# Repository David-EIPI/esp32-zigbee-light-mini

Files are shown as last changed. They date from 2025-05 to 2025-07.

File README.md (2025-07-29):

# esp32-zigbee-light-mini

Compact version of the remotely controlled indoor light based on ESP32-H2 and Home Assistant.

## Overview

This is a compact version of the [esp32-zigbee-light](https://github.com/David-EIPI/esp32-zigbee-light "Remotely controlled indoor light powered by ESP32-H2"), small enough to fit into an in-ceiling electrical box, enabling neat conversion of a standard ceiling fixture into a smart light.

This project utilizes a compact WROOM-03 module with an edge connector. The overall design follows [esp32-zigbee-light](https://github.com/David-EIPI/esp32-zigbee-light "Remotely controlled indoor light powered by ESP32-H2").

## Firmware

The firmware is written in C and built with `idf.py`. It implements a zero-crossing detector for TRIAC-based dimming and supports the **HLK-LD2420S** mmWave motion sensor with adjustable sensing distance. The firmware exposes 7 endpoints and 13 clusters:

* **6 Analog Output clusters** (configuration)
* **2 Analog Input clusters** (presence detection distance, calibration control)
* **2 Binary Input clusters** (motion state, light state)
* **1 Multistate Value cluster** (operation mode)
* **1 OnOff cluster** (dimming enable control)
* **1 Temperature cluster** (MCU internal temperature)

This design includes an additional temperature cluster due to the compact, enclosed setup. Monitoring internal temperature becomes important in this system.

See [here](https://github.com/David-EIPI/esp32-zigbee-light/blob/main/BUILD.md) instructions on building the firmware using `idf.py` on Linux.

### Sensor calibration

In this compact design, the LD2420s motion sensor has shown somewhat unstable output. Even without any motion, it occasionally "detects" activity at random distances. This likely results from EMI generated by the power supply, the microcontroller core, or the radio. Fortunately, the LD2420s sensor supports programmable signal thresholds, allowing for in-place calibration. The calibration approach and initial code are based on the [ESPHome LD2420 plugin](https://github.com/esphome/esphome/blob/dev/esphome/components/ld2420 "ESPHome LD2420 plugin").

Calibration is initiated by writing a numerical value (interpreted as calibration duration in seconds) to the Analog Input cluster at Endpoint 2. A ZHA quirk can provide a button to conveniently start calibration.

## Hardware

Schematics and PCB layout were created using KiCad. The board integrates an AC-DC power supply, ESP32-H2 controller, LD2420s sensor, TRIAC, and associated control circuitry. Input protection includes a current fuse, thermal fuse, and a TVS diode. The TRIAC control circuit matches the one in [esp32-zigbee-light](https://github.com/David-EIPI/esp32-zigbee-light "Remotely controlled indoor light powered by ESP32-H2").

### Power supply

The largest component on the board is the AC-DC converter.
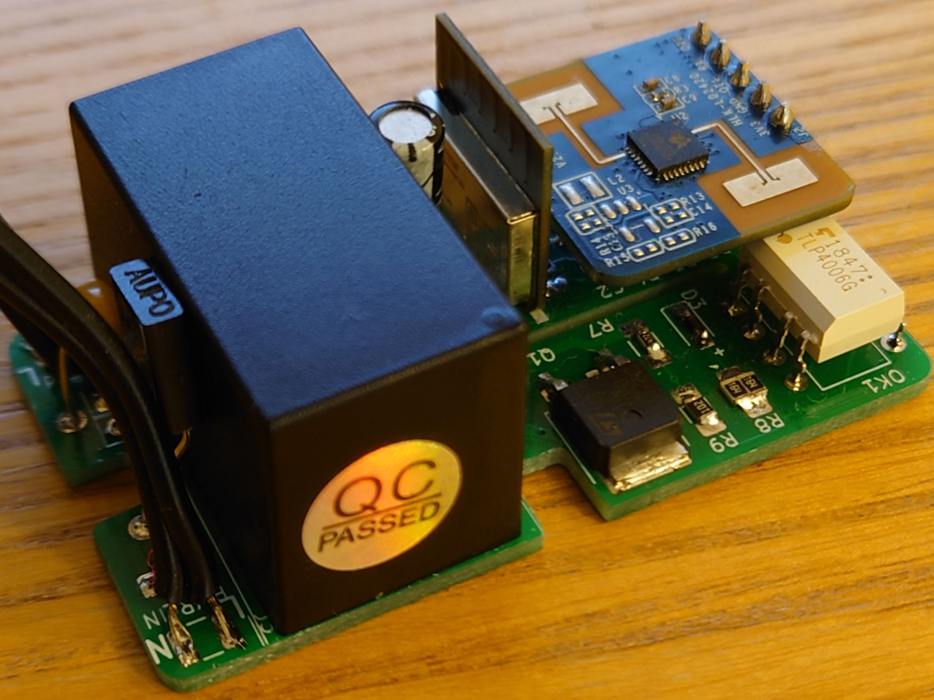
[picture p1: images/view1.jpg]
Board view Assembled board, AC-DC view

This is the HLK-2M03 from HiLink, an isolated 3.3 V, 600 mA converter.  Measured ESP32 consumption is approximately 20 mA during RF transmission, and the documented LD2420s consumption averages around 50 mA, with occasional peaks of about 70 mA. Including the optocoupler current, total demand should not exceed 100 mA. HLK-2M03 is somewhat oversized for this design but smaller modules appear unavailable.

### ESP32-H2 Wroom-03 module

The module is designed for vertical mounting to conserve PCB space. Its height above the board is 16 mm, which is lower than the AC-DC module, thus not affecting the overall dimensions.

Soldering this module presented some challenges:

First, the slot recommended by the datasheet is excessively wide, causing the module to fit loosely and leaving large air gaps difficult to bridge with solder. To resolve this, I soldered short wire segments to the pads as guides, but the result still looks ugly. I wonder if wave soldering would work for this module.

Second, programming is performed via small test pads (USB or serial port). In the datasheet I did not find any recommendations regarding manufacturer-supported programming fixtures. While some users create custom 3D-printed jigs, I opted to solder free-hanging wires directly to the module’s USB pads, enabling programming and debugging after board assembly.
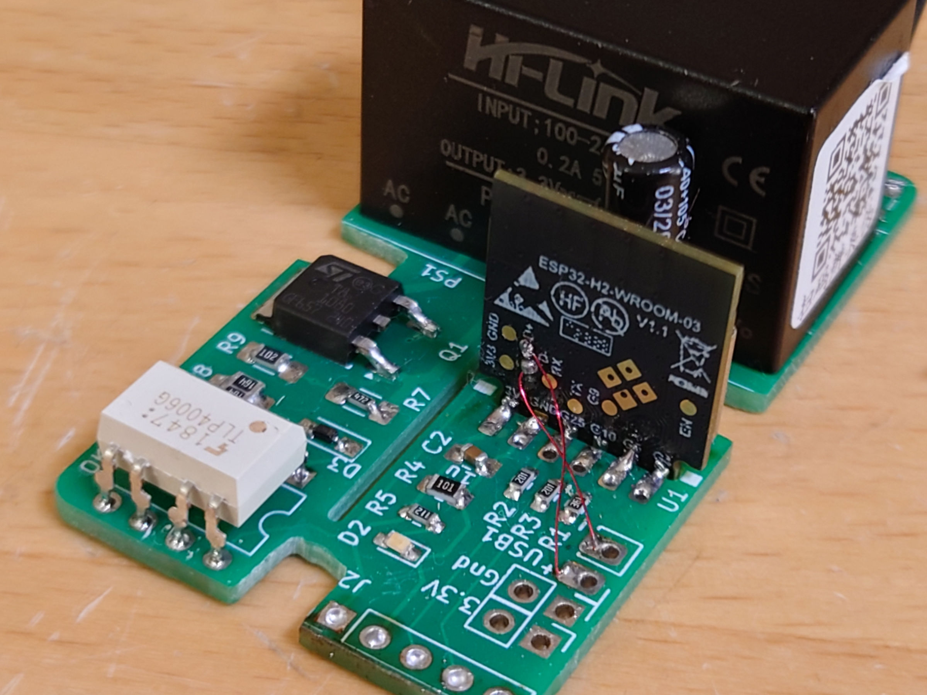
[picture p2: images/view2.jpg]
ESP32-H2 Wroom module Assembled board, ESP32H2 view


### Enclosure

The PCB was designed to fit one of the many enclosures sold on AliExpress. Many sellers offer identical boxes; I purchased this one below:
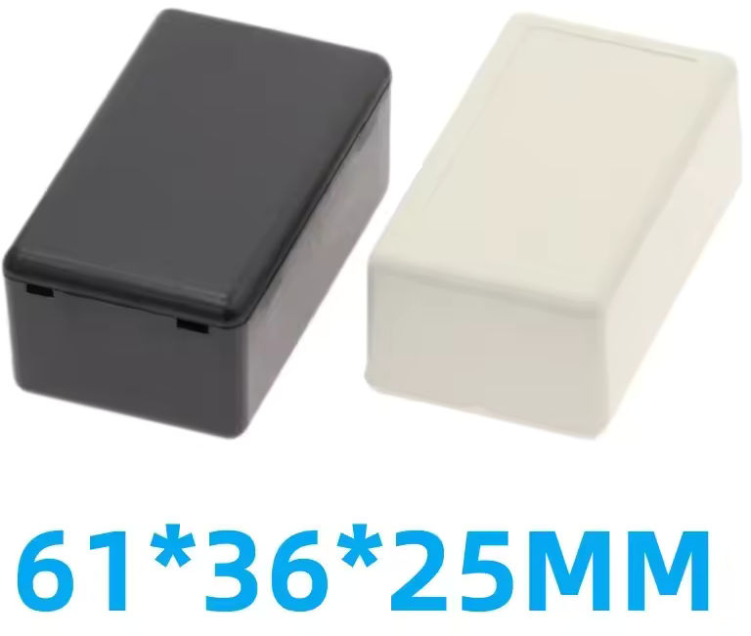
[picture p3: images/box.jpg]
Enclosure box


The assembled board fits almost perfectly, though slight filing was necessary on the cutouts made for the mounting posts. The inner height of the enclosure just accommodates the AC-DC converter, leaving insufficient room to place the board on top of the mounting posts. Instead, I made small cutouts around the posts, allowing the board to sit flat at the bottom.
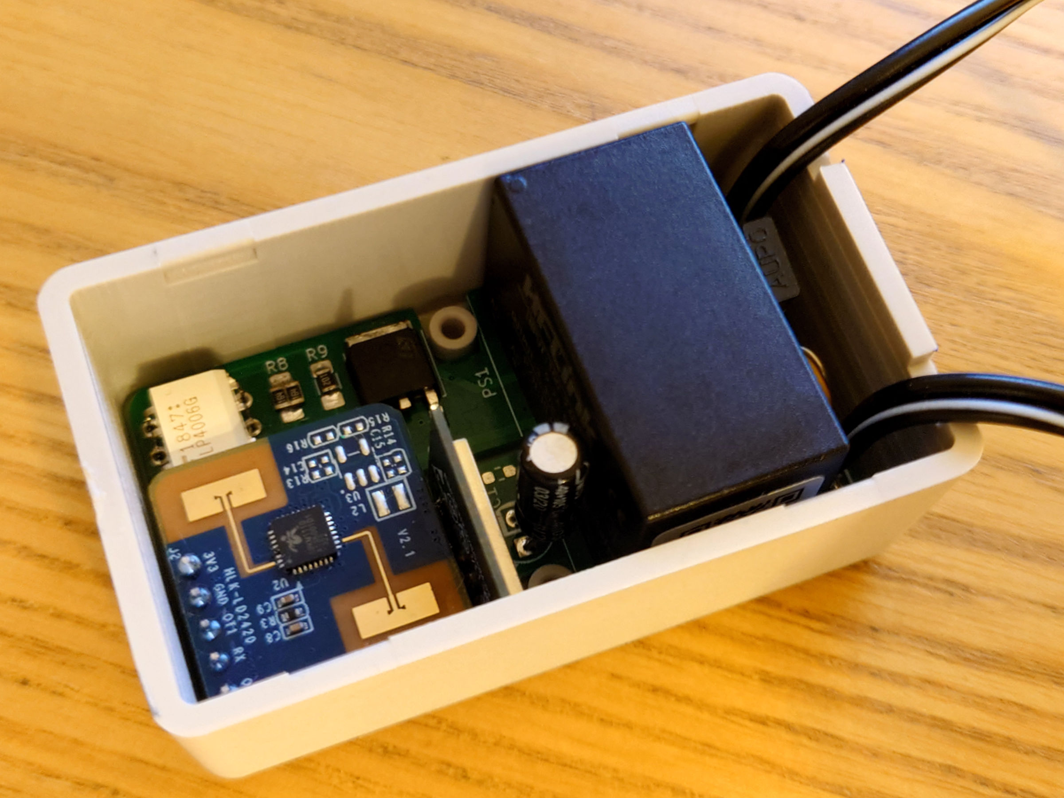
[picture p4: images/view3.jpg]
Assembled board in enclosure Assembled board in the enclosure


To ensure proper fit, the board's bottom side needed to remain completely flat. The AC-DC converter’s leads were trimmed flush, and minimal solder was used to avoid bulges. All other through-hole components were soldered from the top side while pressing the board firmly onto a flat surface, which is why they “hover” above the board surface.
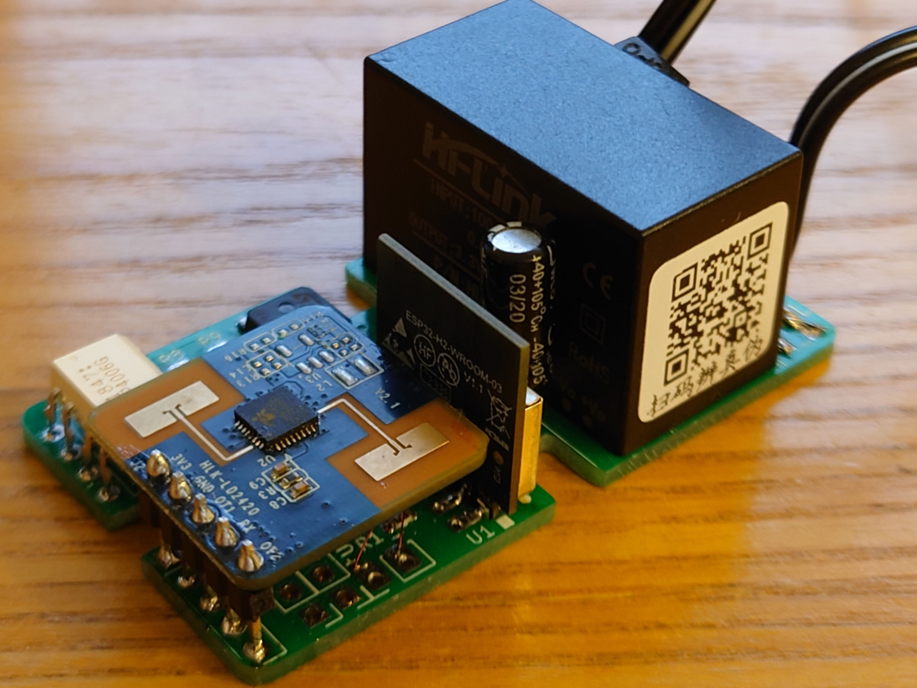
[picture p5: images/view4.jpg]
Assembled board, front view


The enclosure features convenient side-wall cutouts for wiring; however, matching cutouts on the lid’s inner rim were missing and had to be manually added. Below is the final assembled enclosure, shown alongside a CR2032 battery for scale reference:
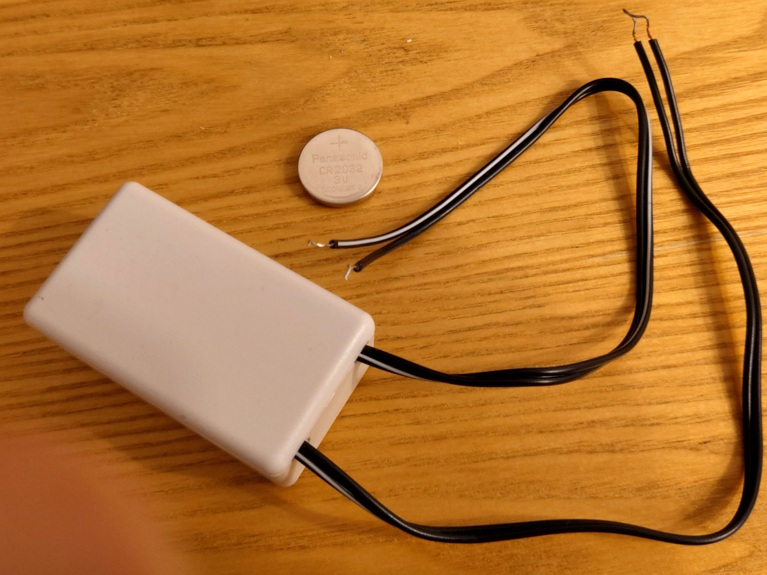
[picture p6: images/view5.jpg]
Assembled box


## ZHA Quirk

The ZHA quirk supporting this device is essentially identical to that in the [esp32-zigbee-light](https://github.com/David-EIPI/esp32-zigbee-light "Remotely controlled indoor light powered by ESP32-H2") project, with only minor additions required to enable sensor calibration requests. This functionality can be implemented in two ways:

* Using the `.number()` method, which defaults to a CONFIG entity displayed as a slider. Setting this slider triggers calibration for the selected duration.
* Using the `.write_attr_butt()` method, creating a button that sets a predefined attribute value upon pressing.

I have left both methods are in the quirk file for reference.
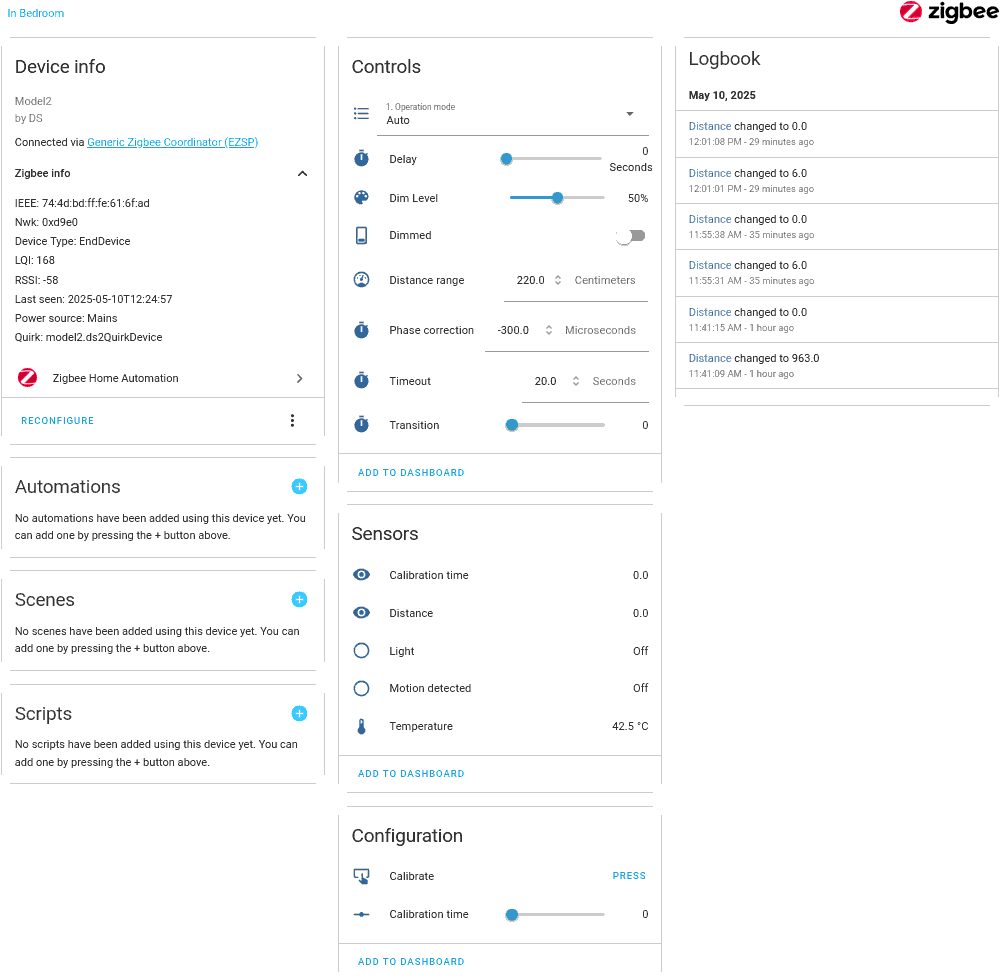
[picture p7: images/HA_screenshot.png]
Home Assistant device page


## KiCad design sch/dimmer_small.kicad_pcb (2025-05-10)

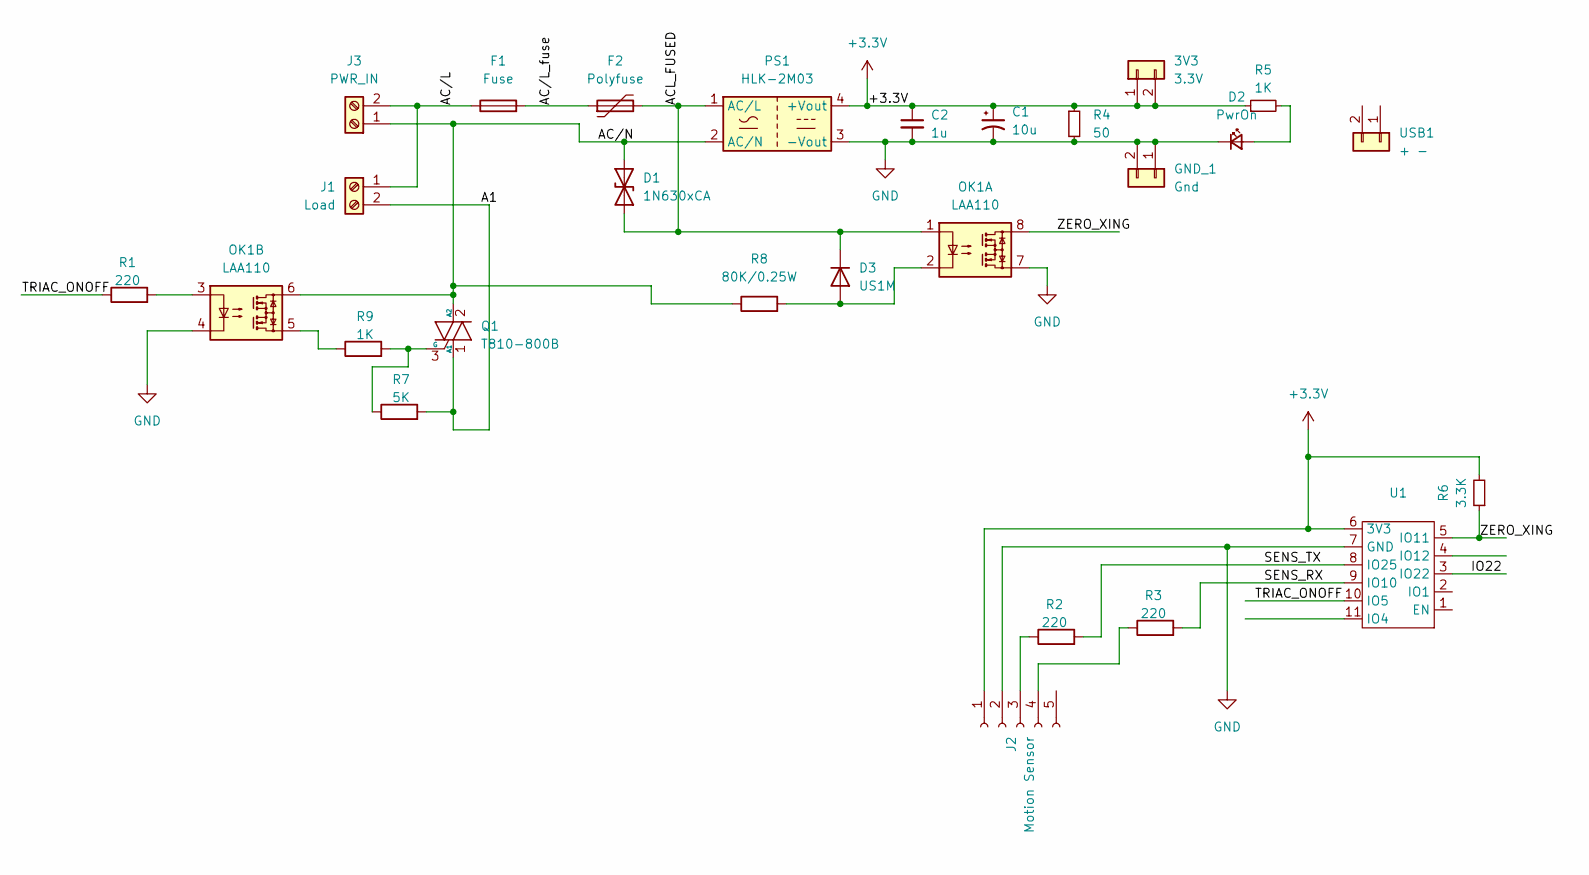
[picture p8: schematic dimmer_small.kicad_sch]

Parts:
3V3: 3.3V; PinHeader_1x02_P2.54mm_Vertical
C1: 10u; CP_Radial_D5.0mm_P2.50mm
C2: 1u; C_0805_2012Metric_Pad1.18x1.45mm_HandSolder
D1: 1N630xCA; PinHeader_2x01_P2.54mm_Vertical
D2: PwrOn; LED_0603_1608Metric_Pad1.05x0.95mm_HandSolder
D3: US1M; Nexperia_CFP3_SOD-123W
F1: Fuse; Fuse_1206_3216Metric_Pad1.42x1.75mm_HandSolder
F2: Polyfuse; Fuse_Bourns_MF-RHT1000
GND_1: Gnd; PinHeader_1x02_P2.54mm_Vertical
J1: Load; Fuse_1210_3225Metric
J2: Motion Sensor; PinHeader_1x05_P2.54mm_Vertical
J3: PWR_IN; Fuse_1210_3225Metric
OK1: LAA110; DIP-8_W7.62mm
PS1: HLK-2M03; Converter_ACDC_Hi-Link_HLK-2Mxx
Q1: T810-800B; TO-252-2
R1, R2, R3: 220; R_0603_1608Metric_Pad0.98x0.95mm_HandSolder
R4: 50; R_0805_2012Metric_Pad1.20x1.40mm_HandSolder
R5: 1K; R_0603_1608Metric_Pad0.98x0.95mm_HandSolder
R6: 3.3K; R_0603_1608Metric_Pad0.98x0.95mm_HandSolder
R7: 5K; R_1206_3216Metric_Pad1.30x1.75mm_HandSolder
R8: 80K/0.25W; R_1206_3216Metric_Pad1.30x1.75mm_HandSolder
R9: 1K; R_1206_3216Metric_Pad1.30x1.75mm_HandSolder
U1: ESP32-H2-WROOM-03
USB1: + -; PinHeader_1x02_P2.54mm_Vertical

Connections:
+3.3V: 3V3.1, 3V3.2, C1.1, C2.1, J2.1, PS1.4 (+Vout), R4.1, R5.1, R6.2, U1.6 (3V3)
/A1: J1.2, Q1.1 (A1), R7.2
/ACL_FUSED: D1.1 (A1), D3.1 (K), F2.2, OK1.1, PS1.1 (AC/L)
/AC/L: F1.1, J1.1, J3.2
/AC/L_fuse: F1.2, F2.1
/AC/N: D1.2 (A2), J3.1, OK1.6, PS1.2 (AC/N), Q1.2 (A2), R8.1
/IO22: U1.3 (IO22)
/SENS_RX: R3.2, U1.9 (IO10)
/SENS_TX: R2.2, U1.8 (IO25)
/TRIAC_ONOFF: R1.1, U1.10 (IO5)
/ZERO_XING: OK1.8, R6.1, U1.5 (IO11)
GND: C1.2, C2.2, D2.1 (K), GND_1.1, GND_1.2, J2.2, OK1.4, OK1.7, PS1.3 (-Vout), R4.2, U1.7 (GND)
unnamed: D2.2 (A), R5.2
unnamed: D3.2 (A), OK1.2, R8.2
unnamed: J2.3, R2.1
unnamed: J2.4, R3.1
unnamed: OK1.3, R1.2
unnamed: OK1.5, R9.1
unnamed: Q1.3 (G), R7.1, R9.2

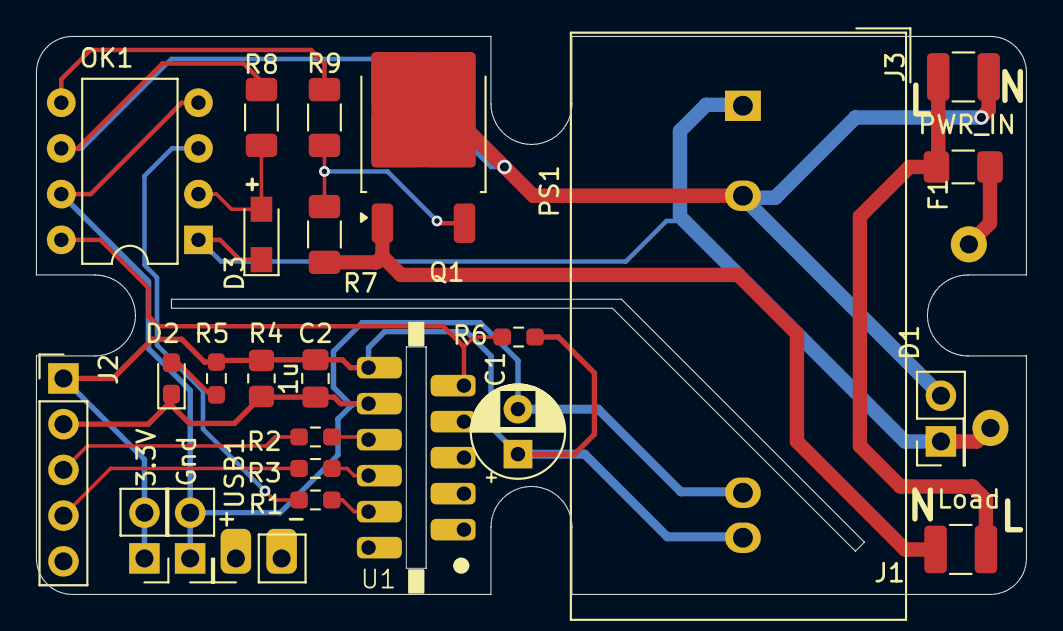
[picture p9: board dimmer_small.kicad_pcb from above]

Board: 2 copper layers, 55.0 x 31.0 mm, 26 parts (1 on the bottom side), 18 nets.

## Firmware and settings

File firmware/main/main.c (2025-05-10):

/*
 * SPDX-FileCopyrightText: 2021-2024 Espressif Systems (Shanghai) CO LTD
 *
 * SPDX-License-Identifier: CC0-1.0
 *
 * Zigbee HA_on_off_light Example
 *
 * This example code is in the Public Domain (or CC0 licensed, at your option.)
 *
 * Unless required by applicable law or agreed to in writing, this
 * software is distributed on an "AS IS" BASIS, WITHOUT WARRANTIES OR
 * CONDITIONS OF ANY KIND, either express or implied.
 */

#include "freertos/FreeRTOS.h"
#include "freertos/task.h"
#include "esp_check.h"
#include "esp_zigbee_core.h"
#include "esp_log.h"
#include "nvs_flash.h"
#include "ha/esp_zigbee_ha_standard.h"
#include "driver/gpio.h"
#include "driver/temperature_sensor.h"
#include "main.h"
#include "clock.h"
#include "ld2420_comm.h"
#include "triac_dimmer.h"

#if !defined ZB_ED_ROLE
#error Define ZB_ED_ROLE in idf.py menuconfig to compile light (End Device) source code.
#endif

static const char *TAG = "APP_MAIN";



enum _operation_modes {
    OPMODE_AUTO = 1,
    OPMODE_ON = 2,
    OPMODE_OFF = 3,
};

static uint16_t operation_mode = OPMODE_AUTO;
static bool enable_dimmed_mode = false;
static int prev_motion_detected = 0;
static int light_state = 1, prev_light_state = 0;
static int32_t light_delay = 2; // seconds, delay after motion detection
static int32_t light_timeout = 10; // seconds, time to keep the light on after motion has stopped
static int32_t light_dim_level = DIM_LEVEL_MAX/2;

static uint64_t light_time_on = 0;
static uint64_t no_motion_time = 0;
static gptimer_handle_t timer = 0;
static const uint32_t timer_resolution = 10 * 1000;

static const unsigned indication_led_pin = 13;

TaskHandle_t dimmerTaskHandle = NULL;

static temperature_sensor_handle_t temp_handle = NULL;
static float temperature_sensor_value = 0;

/********************* Define functions **************************/
static void bdb_start_top_level_commissioning_cb(uint8_t mode_mask)
{
    ESP_ERROR_CHECK(esp_zb_bdb_start_top_level_commissioning(mode_mask));
}

static const int ZB_INIT_FAIL_COUNT_TO_REBOOT = 60;
static const int ZB_ZDO_FAIL_COUNT_TO_REBOOT = 10;
static int zb_fail_count = 0;


static struct {
    char     description[16];
    float    min_present;
    float    max_present;
    float    present_value;
    float    resolution;
    uint16_t status_flags;
    uint16_t units;
    uint32_t app_type;
    volatile int32_t *value_ptr;
    char     nvs_key[8];
} analog_output_attr_values[] = {
    {
    .description = "\x07" "Timeout",
    .min_present = 1,
    .max_present = 3600,
    .present_value = 20,
    .resolution = 1,
    .status_flags = 0,
    .units = 73, /* 73 = seconds */
    .app_type = 14 << 16, /* 14 = timer */
//    .value_ptr = &motionTimeout,
    .value_ptr = &light_timeout,
    .nvs_key = "AO_00",
    },

    {
    .description = "\x05" "Delay",
    .min_present = 0,
    .max_present = 20,
    .present_value = 2,
    .resolution = 1,
    .status_flags = 0,
    .units = 73, /* 73 = seconds */
    .app_type = 14 << 16, /* 14 = timer */
    .value_ptr = &light_delay,
    .nvs_key = "AO_01",
    },

    {
    .description = "\x0e" "Distance range",
    .min_present = 1,
    .max_present = 1000,
    .present_value = 200,
    .resolution = 1,
    .status_flags = 0,
    .units = 118, /* 118 = cm */
    .app_type = 2 << 16, /* 2 = Gauge */
    .value_ptr = &motionThreshold,
    .nvs_key = "AO_02",
    },

    {
    .description = "\x09" "Dim level",
    .min_present = 0,
    .max_present = 100,
    .present_value = 50,
    .resolution = 1,
    .status_flags = 0,
    .units = 98, /* 98 = % */
    .app_type = 15 << 16, /* 15 = palette */
    .value_ptr = &light_dim_level,
    .nvs_key = "AO_03",
    },

    {
    .description = "\x0b" "Phase corr.",
    .min_present = -10000,
    .max_present = 10000,
    .present_value = 0,
    .resolution = 1,
    .status_flags = 0,
    .units = 194, /* 194 = microseconds */
    .app_type = 14 << 16, /* 15 = timer */
    .value_ptr = &phaseCorrection_us,
    .nvs_key = "AO_04",
    },

    {
    .description = "\x0a" "Transition",
    .min_present = 0,
    .max_present = 15,
    .present_value = 0,
    .resolution = 1,
    .status_flags = 0,
    .units = 95,
    .app_type = 14 << 16, /* 15 = timer */
    .value_ptr = &transitionTime,
    .nvs_key = "AO_05",
    },


};



static struct {
    char     *states_text;
    char     description[16];
    uint16_t *present_value_ptr;
    uint16_t status_flags;
    uint16_t number_of_states;
    char     nvs_key[8];
} multistate_attr_values[] = {
    {

/* Binary format for the ZCL string array: 1. type; 2. count; 3. array of strings.
*/
    .states_text = "\x42"       /*ESP_ZB_ZCL_ATTR_TYPE_CHAR_STRING = 0x42 */
                    "\x04\x00"  /* Element count */
                    "\x04" "Auto"
                    "\x02" "On"
                    "\x03" "Off",
    .description = "\x0e" "Operation mode",
    .present_value_ptr = &operation_mode,
    .status_flags = 0,
    .number_of_states = 3,
    .nvs_key = "MV_00",
    }
};

char light_on_binary_desc[] = "\x0b" "Light is on";
char motion_binary_desc[] = "\x0f" "Motion detected";

const char ZB_STORAGE_NAMESPACE[] = "zb_storage";

static void init_gpio(void)
{
    const gpio_config_t io_conf = {
        .intr_type = GPIO_INTR_DISABLE,
        .mode = GPIO_MODE_OUTPUT,
        .pin_bit_mask = (1ULL << indication_led_pin),
        .pull_down_en = 0,
        .pull_up_en = 0,
    };

    gpio_config(&io_conf);
    gpio_set_level(indication_led_pin, 1);
}

/* Signal the dimmer task to disable its sync source and stop the timer
    to avoid light flash when the source pin is disabled at restart. */
static void stop_dimmer_and_restart(void)
{
    stopDimmer = 1;
    vTaskDelay(pdMS_TO_TICKS(200));
    esp_restart();
}


void esp_zb_app_signal_handler(esp_zb_app_signal_t *signal_struct)
{
    uint32_t *p_sg_p       = signal_struct->p_app_signal;
    esp_err_t err_status = signal_struct->esp_err_status;
    esp_zb_app_signal_type_t sig_type = *p_sg_p;
    uint8_t min_lqi;

    switch (sig_type) {
    case ESP_ZB_NLME_STATUS_INDICATION:
        ESP_LOGI(TAG, "%s, status: 0x%x\n", esp_zb_zdo_signal_to_string(sig_type), *(uint8_t *)esp_zb_app_signal_get_params(p_sg_p));
        break;
    case ESP_ZB_ZDO_SIGNAL_SKIP_STARTUP:
        ESP_LOGI(TAG, "Zigbee stack initialized");
        esp_zb_bdb_start_top_level_commissioning(ESP_ZB_BDB_MODE_INITIALIZATION);
        min_lqi = esp_zb_secur_network_min_join_lqi_get();
        ESP_LOGI(TAG, "Min LQI = %u", (unsigned)min_lqi);
        esp_zb_secur_network_min_join_lqi_set(0);
        break;
    case ESP_ZB_BDB_SIGNAL_DEVICE_FIRST_START:
    case ESP_ZB_BDB_SIGNAL_DEVICE_REBOOT:
        if (err_status == ESP_OK) {
            ESP_LOGI(TAG, "Device started up in %s factory-reset mode", esp_zb_bdb_is_factory_new() ? "" : "non");
            if (esp_zb_bdb_is_factory_new()) {
                ESP_LOGI(TAG, "Start network steering");
                esp_zb_bdb_start_top_level_commissioning(ESP_ZB_BDB_MODE_NETWORK_STEERING);
            } else {
                ESP_LOGI(TAG, "Device rebooted");
            }

            zb_fail_count = 0;
        } else {
            /* commissioning failed */

            if (ZB_INIT_FAIL_COUNT_TO_REBOOT <= zb_fail_count) {
                ESP_LOGI(TAG, "ZB init has failed too many times. Restarting.");
                stop_dimmer_and_restart();
                break;
            }

            ESP_LOGW(TAG, "Failed to initialize Zigbee stack (status: %s)", esp_err_to_name(err_status));
            esp_zb_scheduler_alarm((esp_zb_callback_t)bdb_start_top_level_commissioning_cb, ESP_ZB_BDB_MODE_INITIALIZATION, 1000);
            zb_fail_count += 1;
        }
        break;
    case ESP_ZB_BDB_SIGNAL_STEERING:
        if (err_status == ESP_OK) {
            esp_zb_ieee_addr_t extended_pan_id;
            esp_zb_get_extended_pan_id(extended_pan_id);
            ESP_LOGI(TAG, "Joined network successfully (Extended PAN ID: %02x:%02x:%02x:%02x:%02x:%02x:%02x:%02x, PAN ID: 0x%04hx, Channel:%d, Short Address: 0x%04hx)",
                     extended_pan_id[7], extended_pan_id[6], extended_pan_id[5], extended_pan_id[4],
                     extended_pan_id[3], extended_pan_id[2], extended_pan_id[1], extended_pan_id[0],
                     esp_zb_get_pan_id(), esp_zb_get_current_channel(), esp_zb_get_short_address());
        } else {
            ESP_LOGI(TAG, "Network steering was not successful (status: %s)", esp_err_to_name(err_status));
            esp_zb_scheduler_alarm((esp_zb_callback_t)bdb_start_top_level_commissioning_cb, ESP_ZB_BDB_MODE_NETWORK_STEERING, 1000);
        }
        break;
    case ESP_ZB_ZDO_SIGNAL_LEAVE:
        ESP_LOGI(TAG, "Leave and network steering initiated.");
//        esp_zb_zcl_reset_nvram_to_factory_default();
        esp_zb_bdb_reset_via_local_action();
        esp_zb_factory_reset();
        esp_zb_scheduler_alarm((esp_zb_callback_t)bdb_start_top_level_commissioning_cb, ESP_ZB_BDB_MODE_NETWORK_STEERING, 1000);
        break;
    case ESP_ZB_ZDO_DEVICE_UNAVAILABLE:
        if (ZB_ZDO_FAIL_COUNT_TO_REBOOT <= zb_fail_count) {
            ESP_LOGI(TAG, "ZDO device unavailable. Restarting.");
            stop_dimmer_and_restart();
            break;
        }
        zb_fail_count += 1;
        __attribute__ ((fallthrough));
    default:
        ESP_LOGI(TAG, "ZDO signal: %s (0x%x), status: %s", esp_zb_zdo_signal_to_string(sig_type), sig_type,
                 esp_err_to_name(err_status));
        break;
    }
}

static struct {
    char     description[16];
    float    min_present;
    float    max_present;
    float    present_value;
    float    resolution;
    uint16_t status_flags;
    uint16_t units;
    uint32_t app_type;
    volatile int32_t *value_ptr;
} analog_input_attr_values[] = {
    {
    .description = DISTANCE_SENSOR_DESC,
    .min_present = 0,
    .max_present = 1000,
    .present_value = 0,
    .resolution = 1,
    .status_flags = 0,
    .units = 118, /* 118 = cm */
    .app_type = 2 << 16, /* 2 = Gauge icon */
    },
    {
    .description = CALIBRATION_DESC,
    .min_present = 0,
    .max_present = 1000,
    .present_value = 0,
    .resolution = 1,
    .status_flags = 0,
    .units = 73, /* 73 = seconds */
    .app_type = 14 << 16, /* 14 = timer */
    .value_ptr = &calibrationTime,
    },
};

#define ANALOG_INPUT_ATTR_FIELD_OFFSET(field) (offsetof(typeof(analog_input_attr_values[0]), field))

static struct {
    int id;
    int offs;
    int access;
} analog_input_attr_offset[] = {
    { ESP_ZB_ZCL_ATTR_ANALOG_INPUT_DESCRIPTION_ID      , ANALOG_INPUT_ATTR_FIELD_OFFSET(description),   .access = ESP_ZB_ZCL_ATTR_ACCESS_READ_ONLY },
    { ESP_ZB_ZCL_ATTR_ANALOG_INPUT_MAX_PRESENT_VALUE_ID, ANALOG_INPUT_ATTR_FIELD_OFFSET(max_present),   .access = ESP_ZB_ZCL_ATTR_ACCESS_READ_ONLY },
    { ESP_ZB_ZCL_ATTR_ANALOG_INPUT_MIN_PRESENT_VALUE_ID, ANALOG_INPUT_ATTR_FIELD_OFFSET(min_present),   .access = ESP_ZB_ZCL_ATTR_ACCESS_READ_ONLY },
    { ESP_ZB_ZCL_ATTR_ANALOG_INPUT_PRESENT_VALUE_ID    , ANALOG_INPUT_ATTR_FIELD_OFFSET(present_value), .access = ESP_ZB_ZCL_ATTR_ACCESS_READ_WRITE | ESP_ZB_ZCL_ATTR_ACCESS_REPORTING },
    { ESP_ZB_ZCL_ATTR_ANALOG_INPUT_RESOLUTION_ID       , ANALOG_INPUT_ATTR_FIELD_OFFSET(resolution),    .access = ESP_ZB_ZCL_ATTR_ACCESS_READ_ONLY },
    { ESP_ZB_ZCL_ATTR_ANALOG_INPUT_STATUS_FLAGS_ID     , ANALOG_INPUT_ATTR_FIELD_OFFSET(status_flags),  .access = ESP_ZB_ZCL_ATTR_ACCESS_READ_WRITE },
    { ESP_ZB_ZCL_ATTR_ANALOG_INPUT_ENGINEERING_UNITS_ID, ANALOG_INPUT_ATTR_FIELD_OFFSET(units),         .access = ESP_ZB_ZCL_ATTR_ACCESS_READ_ONLY },
    { ESP_ZB_ZCL_ATTR_ANALOG_INPUT_APPLICATION_TYPE_ID , ANALOG_INPUT_ATTR_FIELD_OFFSET(app_type),      .access = ESP_ZB_ZCL_ATTR_ACCESS_READ_ONLY }
};

static  esp_zb_zcl_reporting_info_t reporting_info = {
        .direction = ESP_ZB_ZCL_CMD_DIRECTION_TO_SRV,
        .ep = 0, //HA_ANALOG_INPUT_ENDPOINT,
        .cluster_id = ESP_ZB_ZCL_CLUSTER_ID_ANALOG_INPUT,
        .cluster_role = ESP_ZB_ZCL_CLUSTER_SERVER_ROLE,
        .dst.profile_id = ESP_ZB_AF_HA_PROFILE_ID,
        .u.send_info.min_interval = 0,
        .u.send_info.max_interval = 10,
        .u.send_info.def_min_interval = 0,
        .u.send_info.def_max_interval = 10,
        .u.send_info.delta.u16 = 1,
        .attr_id = ESP_ZB_ZCL_ATTR_ANALOG_INPUT_PRESENT_VALUE_ID,
        .manuf_code = ESP_ZB_ZCL_ATTR_NON_MANUFACTURER_SPECIFIC,
    };


#define MULTISTATE_ATTR_FIELD_OFFSET(field) (offsetof(typeof(multistate_attr_values[0]), field))

static struct {
    int id;
    int offs;
    int access;
} multistate_attr_offset[] = {
    { ESP_ZB_ZCL_ATTR_MULTI_VALUE_DESCRIPTION_ID      , MULTISTATE_ATTR_FIELD_OFFSET(description),   .access = ESP_ZB_ZCL_ATTR_ACCESS_READ_ONLY },
//    { ESP_ZB_ZCL_ATTR_MULTI_VALUE_PRESENT_VALUE_ID    , MULTISTATE_ATTR_FIELD_OFFSET(present_value), .access = ESP_ZB_ZCL_ATTR_ACCESS_READ_WRITE | ESP_ZB_ZCL_ATTR_ACCESS_REPORTING },
    { ESP_ZB_ZCL_ATTR_MULTI_VALUE_STATUS_FLAGS_ID     , MULTISTATE_ATTR_FIELD_OFFSET(status_flags),  .access = ESP_ZB_ZCL_ATTR_ACCESS_READ_WRITE },
/* States text attribute is not supported... */
};

static esp_err_t nvs_save_int_attribute(int32_t value, const char *key)
{
    nvs_handle_t handle = 0;
    esp_err_t err = ESP_OK;

//    ESP_LOGI(TAG, "Saving attribute: %s = %ld", key, value);
    ESP_RETURN_ON_ERROR(nvs_open(ZB_STORAGE_NAMESPACE, NVS_READWRITE, &handle), TAG, "Error opening NVS handle!");

    err = nvs_set_i32(handle, key, value);
    if (err != ESP_OK)
    {
        ESP_LOGE(TAG, "Failed to write to NVS (%s)!", esp_err_to_name(err));

    } else {

        err = nvs_commit(handle);
        if (err != ESP_OK)
        {
            ESP_LOGE(TAG, "Failed to commit to NVS (%s)!", esp_err_to_name(err));
        }
    }

    nvs_close(handle);
    return err;
}

static esp_zb_attribute_list_t * create_analog_input_clusters(unsigned idx)
{

    esp_zb_attribute_list_t *esp_zb_analog_input_cluster = esp_zb_zcl_attr_list_create(ESP_ZB_ZCL_CLUSTER_ID_ANALOG_INPUT);
    int nattrs = 0;
    if (esp_zb_analog_input_cluster != NULL) {
        int i;

        for (i = 0; i < lengthof(analog_input_attr_offset); i++) {

	    esp_err_t err = esp_zb_analog_input_cluster_add_attr(esp_zb_analog_input_cluster, analog_input_attr_offset[i].id,
	        ((void*)&analog_input_attr_values[idx]) + analog_input_attr_offset[i].offs);
	    if (ESP_OK == err)
	        nattrs += 1;
        }
    }

    ESP_LOGI(TAG, "Analog input cluster %u created. Attrs: %d", idx, nattrs);
    return esp_zb_analog_input_cluster;
}


static esp_zb_attribute_list_t *create_multistate_cluster(nvs_handle_t handle)
{
    esp_zb_attribute_list_t *esp_zb_multi_cluster = esp_zb_zcl_attr_list_create(ESP_ZB_ZCL_CLUSTER_ID_MULTI_VALUE);

    if (esp_zb_multi_cluster != NULL) {
/* Assemble the cluster from the attributes one by one, because the helper function (esp_zb_multistate_value_cluster_create)
    does not set ACCESS_REPORTING flag on "present_value" attribute.
*/
        int i;
        for (i = 0; i < lengthof(multistate_attr_offset); i++) {
	    esp_zb_multistate_value_cluster_add_attr(esp_zb_multi_cluster, multistate_attr_offset[i].id,
	        ((void*)&multistate_attr_values[0]) + multistate_attr_offset[i].offs );
        }

/*  Attempt to find a saved attribute value */
        int32_t saved_value = 0;
        if (handle && ESP_OK == nvs_get_i32(handle, multistate_attr_values[0].nvs_key, &saved_value)) {
            ESP_LOGI(TAG, "Loaded attribute: %s = %ld", multistate_attr_values[0].nvs_key, saved_value);

/* Do not start up in disabled state */
            if (saved_value == OPMODE_OFF || saved_value > multistate_attr_values[0].number_of_states)
                saved_value = OPMODE_AUTO;

            *multistate_attr_values[0].present_value_ptr = saved_value;
        }

        esp_zb_cluster_add_attr(esp_zb_multi_cluster,
	    ESP_ZB_ZCL_CLUSTER_ID_MULTI_VALUE,
	    ESP_ZB_ZCL_ATTR_MULTI_VALUE_PRESENT_VALUE_ID,
	    ESP_ZB_ZCL_ATTR_TYPE_U16,
	    ESP_ZB_ZCL_ATTR_ACCESS_READ_WRITE | ESP_ZB_ZCL_ATTR_ACCESS_REPORTING,
	    multistate_attr_values[0].present_value_ptr);

    }

    ESP_LOGI(TAG, "Multistate cluster created: %d", (int)(esp_zb_multi_cluster!=NULL));
    return esp_zb_multi_cluster;
}

#define ANALOG_ATTR_FIELD_OFFSET(field) (offsetof(typeof(analog_output_attr_values[0]), field))

static struct {
    int id;
    int offs;
    int access;
} analog_attr_offset[] = {
    { ESP_ZB_ZCL_ATTR_ANALOG_OUTPUT_DESCRIPTION_ID      , ANALOG_ATTR_FIELD_OFFSET(description),   .access = ESP_ZB_ZCL_ATTR_ACCESS_READ_ONLY },
    { ESP_ZB_ZCL_ATTR_ANALOG_OUTPUT_MAX_PRESENT_VALUE_ID, ANALOG_ATTR_FIELD_OFFSET(max_present),   .access = ESP_ZB_ZCL_ATTR_ACCESS_READ_ONLY },
    { ESP_ZB_ZCL_ATTR_ANALOG_OUTPUT_MIN_PRESENT_VALUE_ID, ANALOG_ATTR_FIELD_OFFSET(min_present),   .access = ESP_ZB_ZCL_ATTR_ACCESS_READ_ONLY },
    { ESP_ZB_ZCL_ATTR_ANALOG_OUTPUT_PRESENT_VALUE_ID    , ANALOG_ATTR_FIELD_OFFSET(present_value), .access = ESP_ZB_ZCL_ATTR_ACCESS_READ_WRITE | ESP_ZB_ZCL_ATTR_ACCESS_REPORTING },
    { ESP_ZB_ZCL_ATTR_ANALOG_OUTPUT_RESOLUTION_ID       , ANALOG_ATTR_FIELD_OFFSET(resolution),    .access = ESP_ZB_ZCL_ATTR_ACCESS_READ_ONLY },
    { ESP_ZB_ZCL_ATTR_ANALOG_OUTPUT_STATUS_FLAGS_ID     , ANALOG_ATTR_FIELD_OFFSET(status_flags),  .access = ESP_ZB_ZCL_ATTR_ACCESS_READ_WRITE },
    { ESP_ZB_ZCL_ATTR_ANALOG_OUTPUT_ENGINEERING_UNITS_ID, ANALOG_ATTR_FIELD_OFFSET(units),         .access = ESP_ZB_ZCL_ATTR_ACCESS_READ_ONLY },
    { ESP_ZB_ZCL_ATTR_ANALOG_OUTPUT_APPLICATION_TYPE_ID , ANALOG_ATTR_FIELD_OFFSET(app_type),      .access = ESP_ZB_ZCL_ATTR_ACCESS_READ_ONLY }
};

/* Setup AnalogOutput clusters and add them to the endpoints starting from the provided index. */
static esp_zb_attribute_list_t * create_analog_cluster(unsigned idx, nvs_handle_t handle)
{
    esp_zb_attribute_list_t *esp_zb_analog_cluster = esp_zb_zcl_attr_list_create(ESP_ZB_ZCL_CLUSTER_ID_ANALOG_OUTPUT);
    int nattrs = 0;
    if (esp_zb_analog_cluster != NULL) {

/*  Attempt to find a saved attribute value */
        int32_t saved_value = 0;
        if (handle && ESP_OK == nvs_get_i32(handle, analog_output_attr_values[idx].nvs_key, &saved_value)) {
            *analog_output_attr_values[idx].value_ptr = saved_value;
            ESP_LOGI(TAG, "Loaded attribute: %s = %ld", analog_output_attr_values[idx].nvs_key, saved_value);
        }
        analog_output_attr_values[idx].present_value = *analog_output_attr_values[idx].value_ptr;

        int i;
        for (i = 0; i < lengthof(analog_attr_offset); i++) {
	    esp_err_t err = esp_zb_analog_output_cluster_add_attr(esp_zb_analog_cluster, analog_attr_offset[i].id,
	        ((void*)&analog_output_attr_values[idx]) + analog_attr_offset[i].offs );
	    if (ESP_OK == err)
	        nattrs += 1;
        }
    }

    ESP_LOGI(TAG, "Analog output cluster %u created. Attrs: %d", idx, nattrs);
    return esp_zb_analog_cluster;
}

/* Setup OnOff switch cluster */
static esp_zb_attribute_list_t * create_on_off_cluster(nvs_handle_t handle)
{

    esp_zb_on_off_cluster_cfg_t on_off_cfg = { .on_off = false };

    esp_zb_attribute_list_t *on_off_cluster = esp_zb_on_off_cluster_create(&on_off_cfg);

    return on_off_cluster;
}


static esp_zb_attribute_list_t * create_binary_input_cluster(char *desc, int value)
{
    esp_zb_binary_input_cluster_cfg_t cfg = { false, 0 };
    esp_zb_attribute_list_t * binary_input_cluster = esp_zb_binary_input_cluster_create(&cfg);
    if (desc) {
        ESP_ERROR_CHECK(esp_zb_binary_input_cluster_add_attr(
            binary_input_cluster,
            ESP_ZB_ZCL_ATTR_BINARY_INPUT_DESCRIPTION_ID,
            desc
        ));
    }
    ESP_ERROR_CHECK(esp_zb_cluster_add_attr(binary_input_cluster,
	    ESP_ZB_ZCL_CLUSTER_ID_BINARY_INPUT,
	    ESP_ZB_ZCL_ATTR_BINARY_INPUT_PRESENT_VALUE_ID,
	    ESP_ZB_ZCL_ATTR_TYPE_BOOL,
	    ESP_ZB_ZCL_ATTR_ACCESS_READ_WRITE | ESP_ZB_ZCL_ATTR_ACCESS_REPORTING,
	    &value));

    return binary_input_cluster;
}

/* Setup Temperature Sensor cluster */
static esp_zb_attribute_list_t * create_temperature_cluster(void)
{
    esp_zb_temperature_meas_cluster_cfg_t cfg = { 0, -10 * 100, 80 * 100 };
    esp_zb_attribute_list_t * temperature_measurement_cluster = esp_zb_temperature_meas_cluster_create(&cfg);

    return temperature_measurement_cluster;
}
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
void app_main(void)
{
    init_gpio();

    esp_zb_platform_config_t config = {
        .radio_config = ESP_ZB_DEFAULT_RADIO_CONFIG(),
        .host_config = ESP_ZB_DEFAULT_HOST_CONFIG(),
    };
    ESP_ERROR_CHECK(nvs_flash_init());
    ESP_ERROR_CHECK(esp_zb_platform_config(&config));
    light_driver_init(LIGHT_DEFAULT_OFF);
    init_timer(&timer, timer_resolution);

    xTaskCreate(esp_zb_task, "Zigbee_main", 1024*8, NULL, 2, NULL);
    xTaskCreate(ld2420_task, "uart_rx_task", 1024 * 4, NULL, 1/*configMAX_PRIORITIES - 1*/, NULL);
    xTaskCreate(triac_dimmer_task, "dimmer_task", 1024 * 4, NULL, configMAX_PRIORITIES - 1, &dimmerTaskHandle);

    gpio_set_level(indication_led_pin, 0);

    if (ESP_RST_SW == esp_reset_reason()) /* Do not turn the light on after soft reset */
        light_state = 0;

    light_control_task(NULL);
}

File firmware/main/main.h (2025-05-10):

/*
 * SPDX-FileCopyrightText: 2021-2024 Espressif Systems (Shanghai) CO LTD
 *
 * SPDX-License-Identifier: CC0-1.0
 *
 * Zigbee HA_on_off_light Example
 *
 * This example code is in the Public Domain (or CC0 licensed, at your option.)
 *
 * Unless required by applicable law or agreed to in writing, this
 * software is distributed on an "AS IS" BASIS, WITHOUT WARRANTIES OR
 * CONDITIONS OF ANY KIND, either express or implied.
 */

#include "esp_zigbee_core.h"
#include "light_driver.h"

/* Zigbee configuration */
#define INSTALLCODE_POLICY_ENABLE       false   /* enable the install code policy for security */
#define ED_AGING_TIMEOUT                ESP_ZB_ED_AGING_TIMEOUT_64MIN
#define ED_KEEP_ALIVE                   3000    /* 3000 millisecond */


#define HA_FIRST_ENDPOINT     1
#define HA_DISTANCE_SENSOR_ENDPOINT   HA_FIRST_ENDPOINT
#define HA_CALIBRATION_ENDPOINT       HA_FIRST_ENDPOINT + 1
#define HA_ON_OFF_DIMMER_ENDPOINT     HA_FIRST_ENDPOINT
#define HA_MULTISTATE_ENDPOINT        HA_FIRST_ENDPOINT+1
#define HA_LIGHT_ON_BINARY_ENDPOINT   HA_FIRST_ENDPOINT
#define HA_MOTION_BINARY_ENDPOINT     HA_FIRST_ENDPOINT+1
#define HA_TEMPERATURE_ENDPOINT       HA_FIRST_ENDPOINT


#define ESP_ZB_PRIMARY_CHANNEL_MASK     ESP_ZB_TRANSCEIVER_ALL_CHANNELS_MASK  /* Zigbee primary channel mask use in the example */

/* Basic manufacturer information */
#define MANUFACTURER_NAME "\x02" "DS"      /* Customized manufacturer name */
#define MODEL_IDENTIFIER "\x06" "Model2" /* Customized model identifier */

#define DISTANCE_SENSOR_DESC  "\x08" "Distance"
#define CALIBRATION_DESC  "\x0b" "Calibration"

#define ESP_ZB_ZED_CONFIG()                                         \
    {                                                               \
        .esp_zb_role = ESP_ZB_DEVICE_TYPE_ED,                       \
        .install_code_policy = INSTALLCODE_POLICY_ENABLE,           \
        .nwk_cfg.zed_cfg = {                                        \
            .ed_timeout = ED_AGING_TIMEOUT,                         \
            .keep_alive = ED_KEEP_ALIVE,                            \
        },                                                          \
    }

#define ESP_ZB_DEFAULT_RADIO_CONFIG()                           \
    {                                                           \
        .radio_mode = ZB_RADIO_MODE_NATIVE,                     \
    }

#define ESP_ZB_DEFAULT_HOST_CONFIG()                            \
    {                                                           \
        .host_connection_mode = ZB_HOST_CONNECTION_MODE_NONE,      \
    }

#define lengthof(a) (sizeof(a)/sizeof(a[0]))

#define STRINGIFY(s) STRINGIFY_HELPER(s)
#define STRINGIFY_HELPER(s) #s

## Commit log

2025-05-10 Initial upload.
    [partitions.csv]
2025-05-10 Added schematics and PCB
    [dimmer_small.kicad_pcb, dimmer_small.kicad_sch]
2025-07-29 Move firmware files into own folder
    [partitions.csv]
